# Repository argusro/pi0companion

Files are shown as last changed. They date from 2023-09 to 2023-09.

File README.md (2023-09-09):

<!DOCTYPE html>
<html lang="en">
<head>
    <meta charset="UTF-8">
    <meta name="viewport" content="width=device-width, initial-scale=1.0">
</head>
<body>

<h1>π0companion</h1>

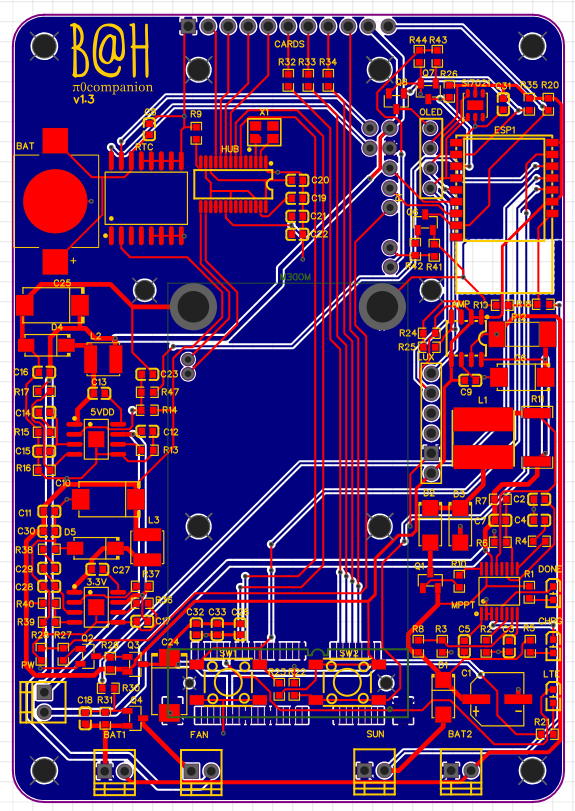
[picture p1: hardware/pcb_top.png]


<p>
We all love our Raspberry Pi projects, and most time using a good PSU is enough to have reliable system.<br>
But what if you want to take your project mobile of off-grid, how to manage the power requirements and beyond that, be able to trust in the continuous operation of your device.<br>
Thinking on that this companion circuit was created. It can be used on usual size Raspberry Pi boards, but considering power consumption for off-grid project this version focus on Pi Zero, any versions.<br>
It adds the following features to your Pi:
</p>

<ul>
    <li><strong>Modem Mini Pcie slot:</strong> 4G modem is a must for any mobile project, and it can include GPS. Based on EG25G/EC25 from Quectel.</li>
    <li><strong>Micro-controller IO/s and Power MGMT:</strong> To add a second layer of IOs and also working as a Watch Dog to the system, a ESP-M2 is used in parallel with the Pi.</li>
    <li><strong>MPPT Charger:</strong> For when a constant power supply is not available, the circuit includes a simple MPPT charger that can be used with Solar Panel or Wind generator.</li>
    <li><strong>HMI:</strong> Direct access to the micro-controller using push buttons and Oled display.</li>
    <li><strong>Environment sensors:</strong> Temperature, humidity, solar/input voltage, battery power monitoring, I2C slot expansion.</li>
    <li><strong>Extra Storage:</strong> Depending on the storage requirement, having extra space to store media and avoid over-using the Pi's main SD is recommended, so an SD card reader is available.</li>
    <li><strong>USB Hub:</strong> Since Pi Zero has a single USB port a local hub is added, to be shared with Pcie modem, SD Card and an extra USB-A Port.</li>
    <li><strong>RTC:</strong> As internet connection is not always available, and even when is it takes some time after boot to adjust the system clock, a local RTC clock was added.</li>
</ul>

<p>The provided code is for the local micro-controller, and the companion code for the Pi for burning ESP and also communicate with the base board.</p>

<h2>Getting Started</h2>

<p>To get started with this project, follow these steps:</p>

<ol>
    <li><strong>Hardware:</strong> You can use development modules for each sensor and the micro-controller, or assemble the suggested PCB.</li>
    <li><strong>Software:</strong> 
    <ul><strong>Compilation:</strong>  This code is for Arduino IDE and requires the following extra libraries to be installed:</li>
    <ul>
        <li><strong>ESP8266WiFi</strong> | You first need to add ESP8266 support on Arduino IDE | https://arduino-esp8266.readthedocs.io/en/latest/installing.html</li>
        <li><strong>Adafruit INA219</strong> | INA219 DC current and voltage sensor | https://github.com/adafruit/Adafruit_INA219</li>
        <li><strong>Arduino Json</strong> | To supports JSON serialization and deserialization | https://arduinojson.org/?utm_source=meta&utm_medium=library.properties</li>
        <li><strong>SparkFun Si7021</strong> | Si7021 Temperature and Humidity sensor | https://github.com/sparkfun/SparkFun_Si7021_Arduino_Library</li>
        <li><strong>Adafruit SSD1306</strong> |  Monochrome OLEDs based on SSD1306 drivers | https://github.com/adafruit/Adafruit_SSD1306</li>
        <li><strong>Adafruit GFX</strong> | Core graphics library for Adafruit displays | https://github.com/adafruit/Adafruit-GFX-Library</li>
        <li><strong>LittleFS</strong> | A little fail-safe filesystem designed for micro-controllers. | https://github.com/littlefs-project/littlefs</li>
    </ul></ul>
    <ul>
    <strong>Deploying:</strong> 
    <ul><li>To burn the code in the circuit is straightforward if you are using a commercial ESP8266/ESP8285 module.</li>
    <li> For the suggested circuit, after compiling copy the .bin file to the Pi and use the esp_burn.sh to upload the code.
    </ul></li></ul>
</ol>

<h2>Usage</h2>

<p>Taking your Pi on the road or just outside adds some other possibilities from the already vast options of use, such as:</p>

<ul>
    <li><strong>Outdoor camera:</strong> Use for security, wildlife or timelapse camera is one obvious application with the Pi Camera modules.</li>
    <li><strong>Mobile Hotspot:</strong> We have a Pi with 4G module, you can create a hotspot very easily.</li>
    <li><strong>IoT Gateway:</strong> You can have multiple remote sensors using WiFi from the Pi to reach the Internet.</li>
    And many other projects.
</ul>

<h2>Observations</h2>

<ul>
    <li>If a commercial modules is used it can be either ESP8266 or ESP8285. In case of the suggested PCB uses ESP8285. In any case, select the correct hardware when compiling.</li>
    <li>PCB was design to fit in a 125x105x70mm plastic case, that are widely available online. You can also fit the batteries and any other module that you will need to use.<br>
    A 3D design [pcb_support.stl] is provided to mount the board inside the suggested case, it can be glued or use screws through the bottom of the case.</li>
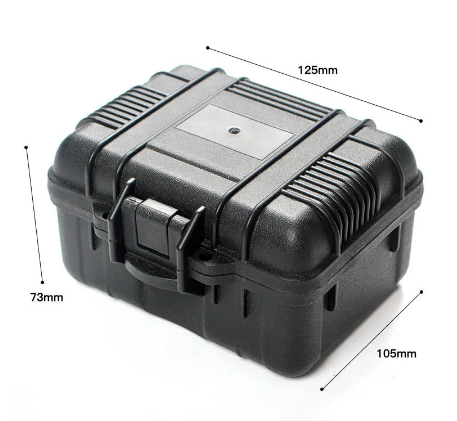
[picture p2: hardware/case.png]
    
    <li>To avoid soldering the required connections to the Pi, pogo testing pins can be used to reach GPIO and USB.</li>
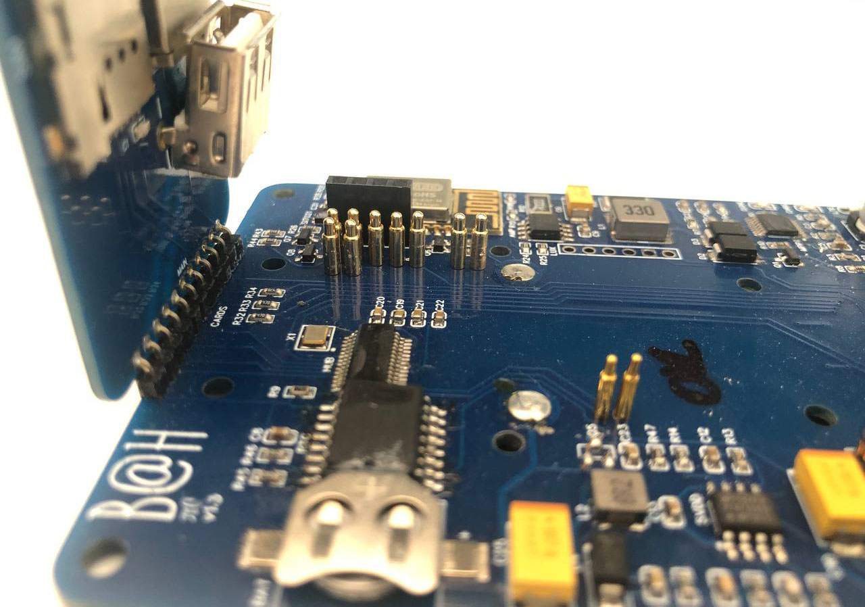
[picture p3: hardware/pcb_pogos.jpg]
    
    <li>To facilitate access a few components were move to a second board, like SD slot, SIM card slot, ESP reset button and USB-A port. This board should be assembled perpendicular to the main PCB.</li>
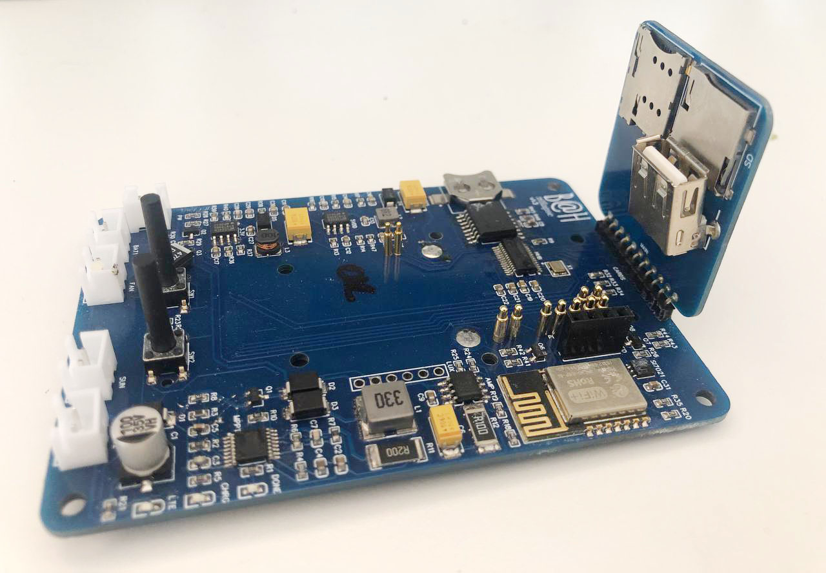
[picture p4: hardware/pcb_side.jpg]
    
    <li>Battery should be a dual cell Li-ion for example 18650, to operate in 8.4V. Two connections for battery are available in parallel to increase capacity. Circuit can also be altered to operate in 12V, just requiring to adjust the MPPT charger output voltage.</li>
    <li>For charging in case of indoor use, any PSU from 18V to 28V with 1A can be used. Charger is configured to provide maximum 1A, but it could be changed to up 5A with some components adjustments and pcb redesign.</li>
</ul>

<h2>Future Work</h2>
<ul>
    <li><strong>Connectivity:</strong> Currently the code will disable the WiFi radio from ESP8285 to reduce power consumption, but a local wireless web interface could be added.</li>
    <li><strong>Micro-controller upgrade:</strong> Plans to change to ESP32 are on the way, allowing more IOs and also Bluetooth connectivity.</li>
    <li><strong>EOL parts:</strong> Some of the components used are reaching their End-Of-Life, but they are still widely available. In any case, newer recommended substitutes should be used in future versions</li>
</ul>

<h2>Contributing</h2>

<p>If you want to contribute to this project, please follow these guidelines:</p>

<ol>
    <li>Fork the repository.</li>
    <li>Create a new branch for your feature or bug fix.</li>
    <li>Make your changes and test them thoroughly.</li>
    <li>Create a pull request to submit your changes.</li>
</ol>

<h2>License</h2>

<p>This project is licensed under the <a href="https://www.gnu.org/licenses/gpl-3.0.html">GNU General Public License v3.0 (GPL-3.0)</a>.</p>
<!--
<h2>Acknowledgments</h2>

<ul>
    <li>Special thanks to <a href="CONTRIBUTORS.md">contributors</a> who have helped with this project.</li>
    <li>Icons made by <a href="https://www.example.com/">Author</a> from <a href="https://www.flaticon.com/">www.flaticon.com</a>.</li>
</ul>
-->
<h2>Contact</h2>

<p>For questions or support, please contact us at <a href="mailto:argusr@me.com">argusr@me.com</a>.</p>

</body>
</html>

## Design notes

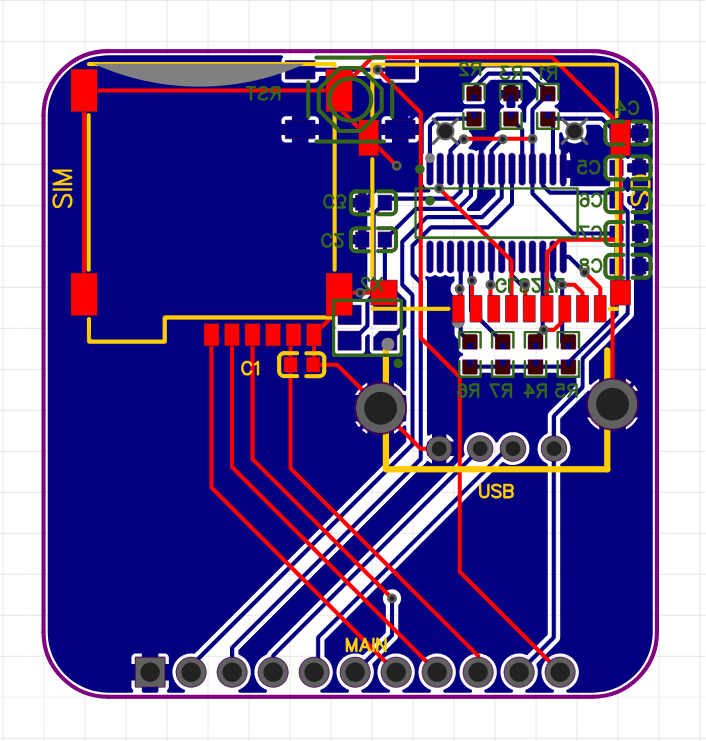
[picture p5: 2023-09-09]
hardware/pcb_cards.png

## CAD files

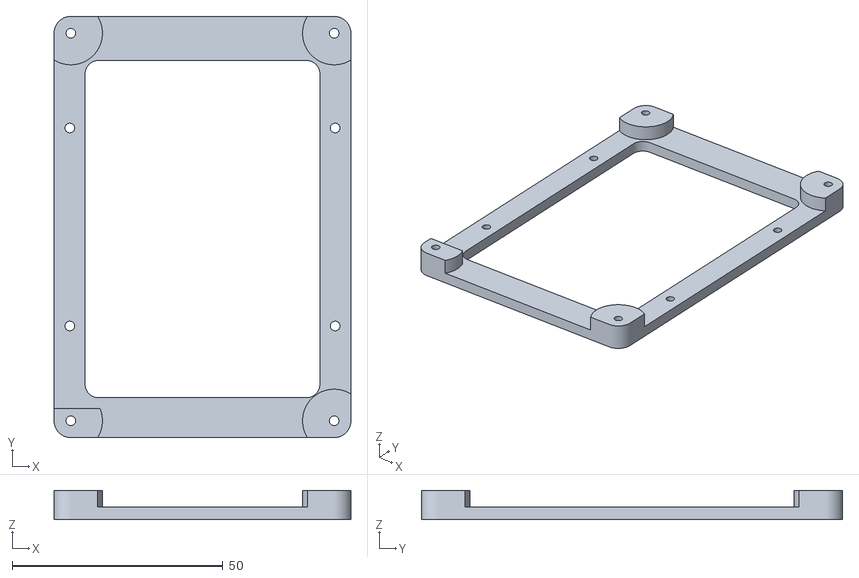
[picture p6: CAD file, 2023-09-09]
hardware/pcb_support.stl
70.5 x 100.0 x 7.00

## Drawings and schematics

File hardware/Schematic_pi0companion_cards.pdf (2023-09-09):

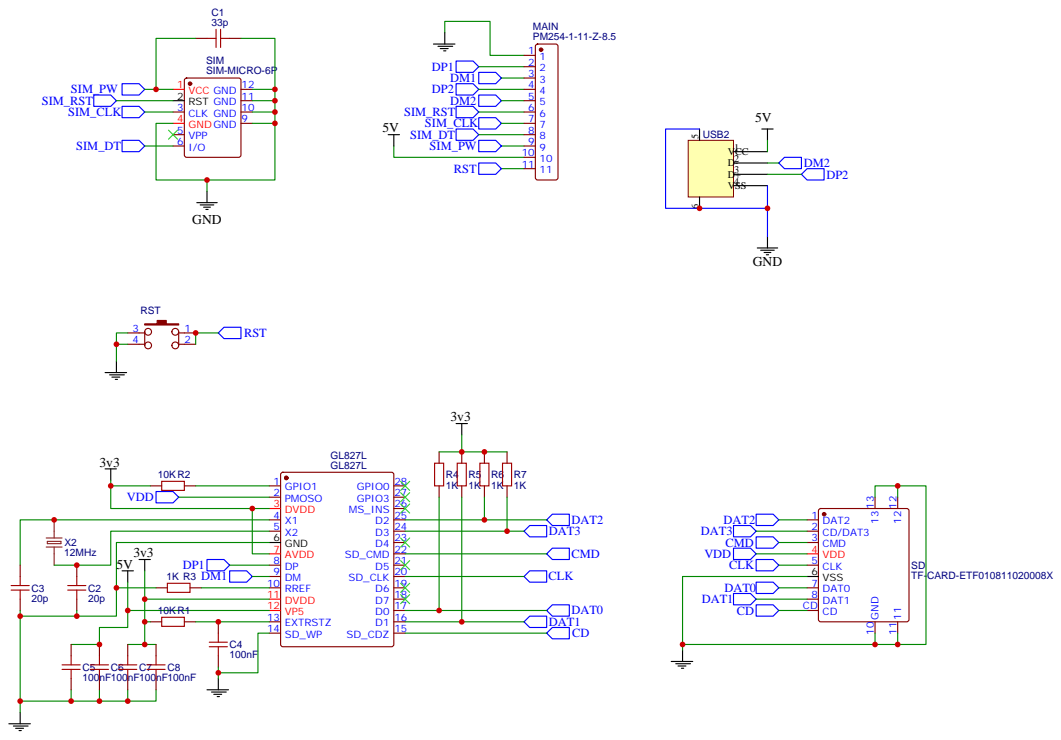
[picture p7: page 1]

Drawn By: Argus Rosenhaim

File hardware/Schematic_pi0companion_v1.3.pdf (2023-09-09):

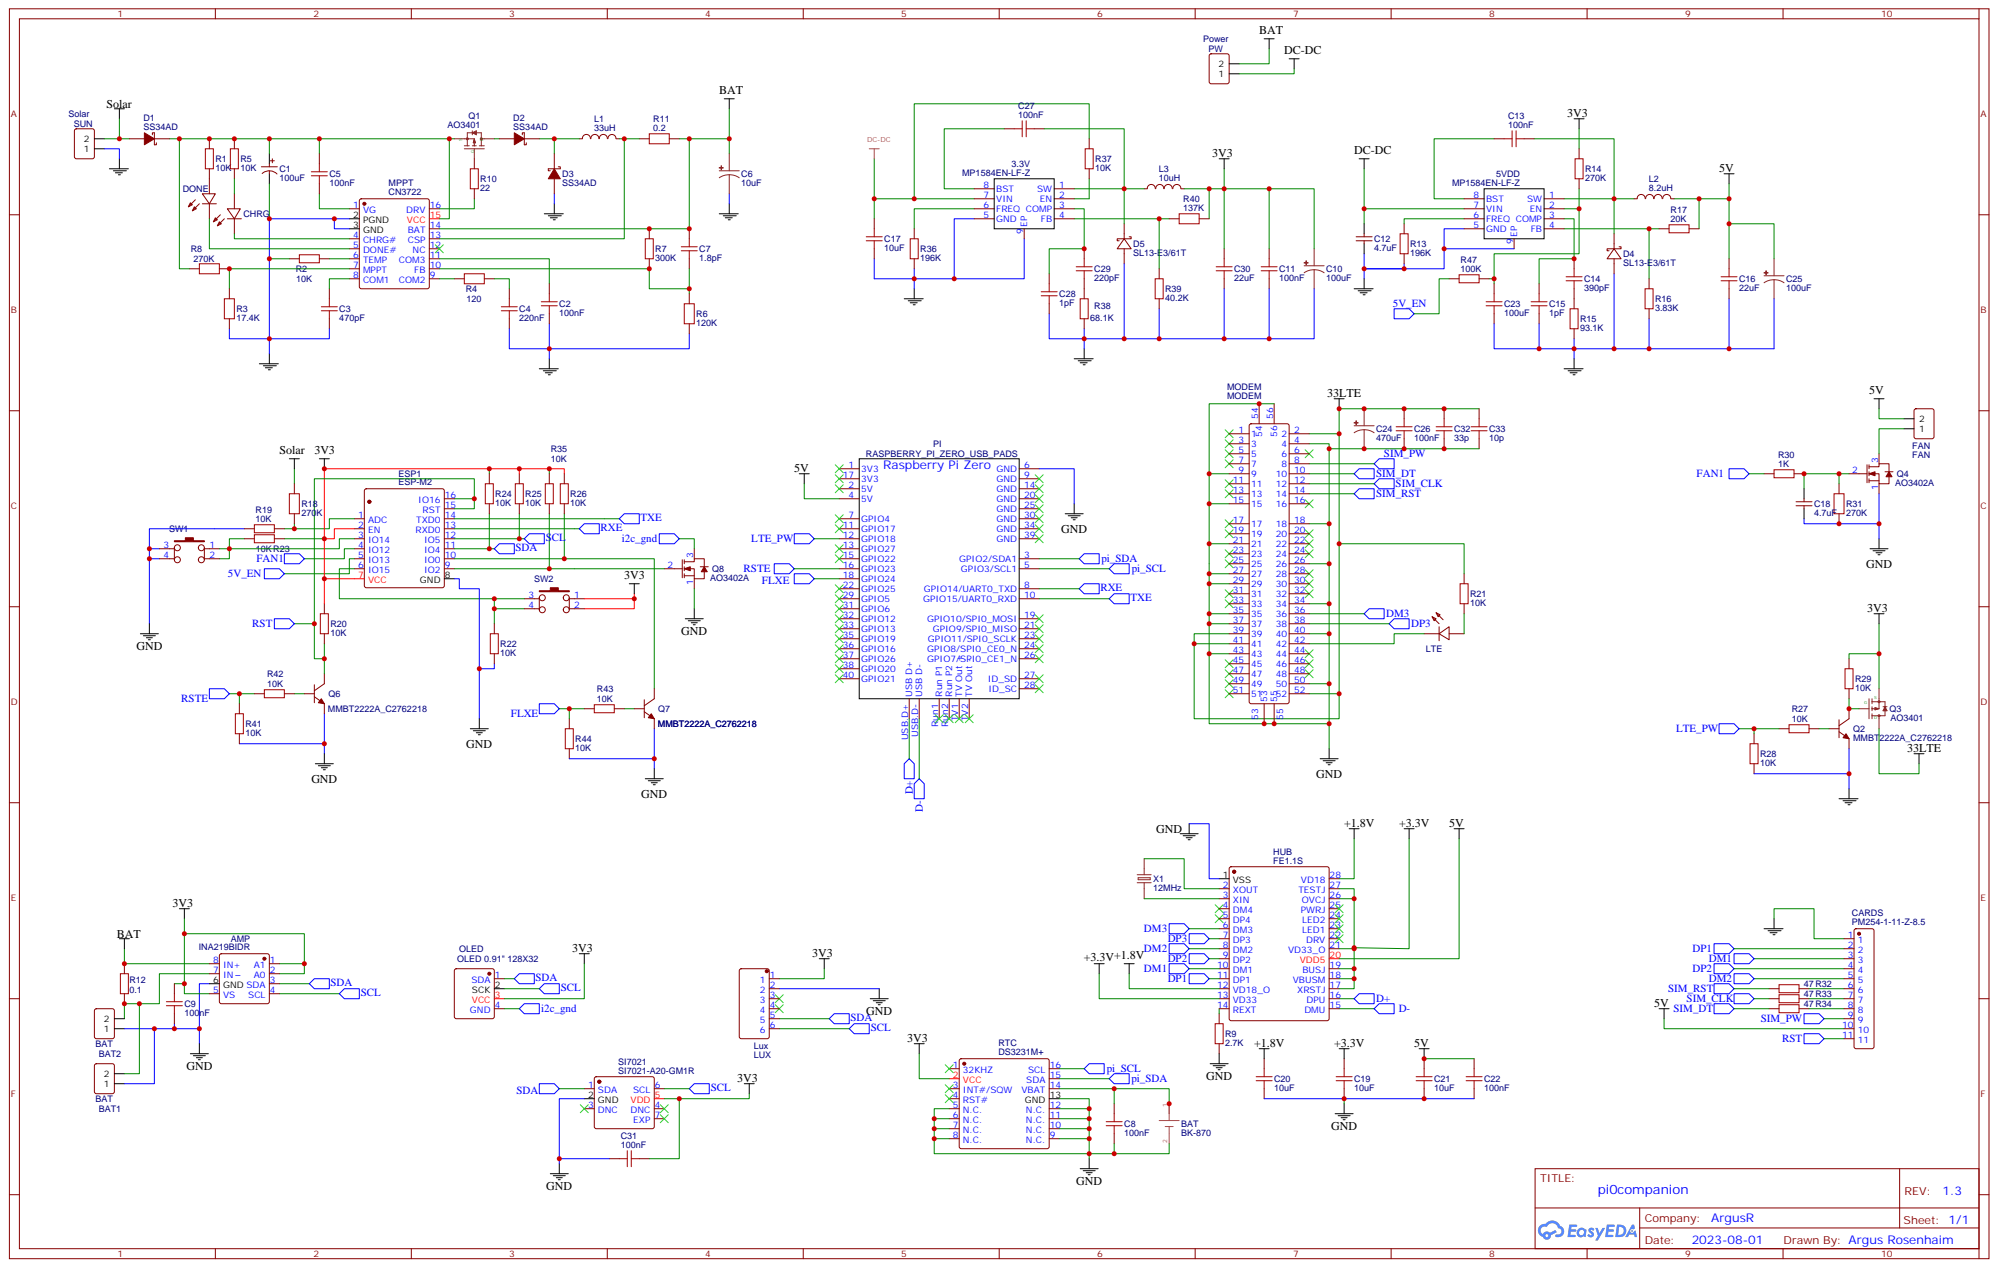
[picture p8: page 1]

MPPT
FB 10 COM3 11 NC 12 CSP 13 BAT 14 VCC 15 DRV 16

Drawn By: Argus Rosenhaim

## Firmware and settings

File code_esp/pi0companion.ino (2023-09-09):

#define Firmware 3.06
#define board_version 1.3
// #define DEBUG

// Iniciate libraries
#include <ESP8266WiFi.h>
#include <Adafruit_INA219.h>
#include <ArduinoJson.h>
#include "SparkFun_Si7021_Breakout_Library.h"
#include <Wire.h>
#include <Adafruit_GFX.h>
#include <Adafruit_SSD1306.h>
#include "LittleFS.h"
#include "logo.h"

// Oled display definitions
#define SCREEN_WIDTH 128 // OLED display width, in pixels
#define SCREEN_HEIGHT 32 // OLED display height, in pixels
#define OLED_RESET     -1 // Reset pin # (or -1 if sharing Arduino reset pin)

// Instantiate Sensors
Adafruit_SSD1306 display(SCREEN_WIDTH, SCREEN_HEIGHT, &Wire, OLED_RESET);
Adafruit_INA219 ina219(0x45);
Weather sensor;

// Time related variables
uint32_t mLastTime = 0;
uint32_t sampleLastTime = 0;
uint32_t last_comm = 0;
long lastDebounceTime = 0;
long lastDebounceTime2 = 0;

// GPIO definitions
#define SW1 14
#define SW2 15
#define fan_in 12
#define soc_pw_pin 13
#define i2c_gnd 2

// Control variables
#define debounceDelay 500
#define wait_before_sleep 15
#define samples 31
#define min_fan_speed 400
float min_voltage=6.8; // Voltage when the system should go in protection mode

// SoC power variables
int count_down = wait_before_sleep - 2;
int count_to_wakeup = 0;
bool SoC_PW = true;
long sleep_period = 0;
bool pi_sleeping = false;
long pi_sleep_start = 0;
bool pi_down = false;
bool low_power_detected = false;
long low_power_sleep = 0;
int low_power_counter = 0;
bool power_off_display = false;
long power_cycle_waiting = 0;
int power_cycle_count = 0;
bool power_cycling = false;
bool ckt_hot = false;
bool wakeup = false;

// Array of samples for each sensor
float hum[samples];
float temp[samples];
float current_mA[samples];
float loadvoltage[samples];
float power_mW[samples];
float solar_v[samples];

// Average variable for each sensor
int valid_samples = 1;
float hum_avg;
float temp_avg;
float current_mA_avg;
float loadvoltage_avg;
float power_mW_avg;
float solar_v_avg;
float busvoltage = 0;
float shuntvoltage = 0;

// byte error, address;
// bool booting = false;
// bool fanin = false;

// Define functions for buttons interruption
void ICACHE_RAM_ATTR switch_1();
void ICACHE_RAM_ATTR switch_2();

// Iniciate variable for device name
String DEVICE = "";

// Variables for menu operation
String confirm_change;
long change_time;
bool new_change_state = false;
bool start_change = false;

// Mobile operators options for menu
char *operators[] = {"Vivo","Claro","Tim","Oi","Vodafone","ThingsMobile"};
#define total_operators 6
int op_id = 0;

void setup() {
  // Disable ESP8266 Radio
  WiFi.forceSleepBegin();
  // Set GPIO modes
  pinMode(SW1, INPUT);
  pinMode(SW2, INPUT);
  pinMode(fan_in, OUTPUT);
  pinMode(soc_pw_pin, OUTPUT);
  pinMode(i2c_gnd, OUTPUT);
  // Power up Pi
  pi_power(true);
  // Power up I2C sensors
  i2c_power(true);
  // Set serial
  Serial.begin(115200);
  Serial.println();
  // Initiate ESP filesystem
  if (!LittleFS.begin()) {
    Serial.println("{'error':'An Error has occurred while mounting LittleFS'}");
    return;
  }
  // Call function to update values stored in the filesystem
  update_from_fs();
  // Initiate Oled display
  display.begin(SSD1306_SWITCHCAPVCC, 0x3C);  // initialize with the I2C addr 0x3C (for the 128x32)
  display.setRotation(2);
  display.clearDisplay();
  // Call logo, stored in logo.h
  display.drawBitmap(0, 0, bah_TL, 128, 32, WHITE);
  display.display();
  delay(3000);
  // Display device name and firmware version
  if (DEVICE.length() > 8 ) display.setTextSize(2);
  else display.setTextSize(3);
  display.setTextColor(WHITE);
  display.clearDisplay();
  display.setCursor(0, 0);
  display.print(DEVICE);
  display.setTextSize(1);
  display.setCursor(100, 24);
  display.print(Firmware);
  display.display();

  delay(3000);
  // Iniciate the interruption watch for the buttons
  attachInterrupt(SW1, switch_1, FALLING);
  attachInterrupt(SW2, switch_2, RISING);
  // Initiate the sensors
  sensor.begin();
  // comment line 67 on SparkFun_Si7021_Breakout_Library.cpp to remove HTU21D Found message
  ina219.begin();
  // Print on serial the wake up message
  uc2pi("boot","uc");
  // Start the internal watchdog
  ESP.wdtDisable();
}

void loop() {
  // Feed the watchdog beast
  ESP.wdtFeed();
  // Check for incoming serial messages from Pi
  if (Serial.available()) {
    serialEvent();
  }
  // If Pi is not in sleeping mode, read the sensors every 200ms
  if(!pi_sleeping){
    if (millis() - sampleLastTime > 200) {
      readSensors();
      sampleLastTime = millis();
    }
  }
  // At every second when Pi sleep command is issued
  if (millis() - mLastTime > 1000) {
    if(pi_sleeping){
//      if (sleep_period > 44000000) sleep_period = 0;  // second protection agaist sleeping more than 12h
      // If the oled is still on
      if(!power_off_display){
        // Clear and update the countdown on the oled display
        display.clearDisplay();
        display.setCursor(0, 0);
        display.print((sleep_period - (millis() - pi_sleep_start))/1000 );
        // If Pi power is still up, display a second countdown for the power down
        if(!pi_down){
          display.setCursor(0, 10);
          display.print((wait_before_sleep*1000 - (millis() - pi_sleep_start))/1000 );       
        }
        display.display();
      }
    }
    // If a power cycle was issued, decrease its counter
    if(power_cycling) power_cycle_count--;    
    mLastTime = millis();
  }
  // Call a few functions on every loop
  update_oled();
  pi_standby();
  pi_power_cycle();
  fan_monitoring();
  monitor_menu_changes();
}

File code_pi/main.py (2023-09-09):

#========================================================================================
#
#   FastAPI App to send messages to Micro-controller(uC)
#
#   This script creates an API to interact with the main board
#
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
#   Dependencies: 
#     apt install fastapi setproctitle uvicorn gunicorn
#     
#
#   Use:  manual: execute run_app.sh
#         service: copy serial_api.service to /etc/systemmd/system/ and activate 
#
#   Version: 1.0 - 09/2023
#   Author: ArgusR <argusr@me.com>
#
#========================================================================================
# Set process name on OS
from setproctitle import setproctitle
setproctitle('serial_api')

import os
import serial
import json
import socket
import logger
import datetime
import subprocess
from fastapi import FastAPI

# Setup the logging
log, master_log = logger.set_logs(os.path.basename(__file__))

# Configuration and database as json files
DB_MGMT="/home/pi/db/mgmt.json"
DB_WEB="/home/pi/db/web.json"

device = socket.gethostname()

app = FastAPI()

# Function to convert variable types
def str_to_bool(s):
    if s == "True":
         return True
    elif s == "False":
         return False
    else:
         raise ValueError

# Function to send serial messages, log and deal with responses.
def get_response(data):
  MGMT = json.loads(open(DB_MGMT).read())
  uC_burning = MGMT["uC_burning"]
  resp_json = {"message":None}
  if uC_burning == "False":
    # Stop pair script responsible for monitoring uC messages
    subprocess.call('sudo pkill -f serial_monitor', shell=True)
    ser = serial.Serial('/dev/serial0', 115200, timeout=1)
    if ser.isOpen():
      ser.write(data.encode('ascii'))
      ser.flush()
      logger.main('debug',"Sent: " + str(data),log, master_log)
      try:
        resp = ser.readline().decode()
        resp_json = json.loads(resp[:-2])
        logger.main('debug',"Received: " + str(resp_json),log, master_log)
        if 'message' in resp_json:
          logger.main('info',resp_json["message"],log, master_log)
        elif 'error' in resp_json:
          logger.main('error',resp_json["error"],log, master_log)
      except Exception as e:
        logger.main('error',"Exception: " + str(e),log, master_log)
        pass
    else:
      logger.main('error',"Serial error",log, master_log)
    ser.close()
    subprocess.Popen('/home/pi/serial_monitor')
  else:
    logger.main('error',"uC currently receiving update, your command will be ignored: " + str(data),log, master_log)
  return resp_json

# Request sensor values from uC
@app.get("/telemetry")
def telemetry():
  msg = {}
  msg["data"] = "telemetry"
  data=json.dumps(msg)
  resp_json = get_response(data)
  return resp_json

# Set fan speed on uC
@app.get("/fan")
def fan(speed: int):
  msg = {}
  msg["fan"] = speed
  data=json.dumps(msg)
  resp_json = get_response(data)
  if 'fan' in resp_json:
    logger.main('info',"Fan speed set to " + str(resp_json["fan"]),log, master_log)
  return resp_json

# Set Pi to sleep, for specific period or until the next day
@app.get("/sleep")
def sleep(interval=None):
  if interval is None:
    WEB = json.loads(open(DB_WEB).read())
    tl_start = int(WEB["shoot"]["start"])
    now = datetime.datetime.now()
    try:
      wake_up = datetime.datetime(now.year,now.month,now.day+1,tl_start)
    except:
      wake_up = datetime.datetime(now.year,now.month+1,1,tl_start)
    tdelta = wake_up - now
    tdelta_sec = int(tdelta.total_seconds())
    logger.main('info',"Sleep interval: " + str(tdelta_sec),log, master_log)
    if tdelta_sec > 64800:  # if is more than 18h, is possibly after midnight
      logger.main('warning',"Trying to sleep more than accepted: " + str(tdelta_sec),log, master_log)
      wake_up = datetime.datetime(now.year,now.month,now.day,tl_start)
      tdelta = wake_up - now
      tdelta_sec = int(tdelta.total_seconds())
      logger.main('info',"Recalculated to: " + str(tdelta_sec),log, master_log)
    sleep_time = tdelta_sec-900  # boot 15 min before the timelapse start time
    if sleep_time < 0:  # avoid negative time
      logger.main('error',"Got a negative value for sleep interval, will replace with 1 min: " + str(sleep_time),log, master_log)
      sleep_time = 60
  else:
    sleep_time = interval

  msg = {}
  msg["sleep"] = sleep_time
  data=json.dumps(msg)
  resp_json = get_response(data)
  if (resp_json["message"].startswith("Wakeup in")):
    logger.main('info',resp_json["message"],log, master_log)
    if interval is None:
      subprocess.call("/home/pi/data_traffic", shell=True)
      subprocess.call("/home/pi/data_traffic clear", shell=True)
    subprocess.call("sudo shutdown now", shell=True)
  else:
    logger.main('error',"Didn't get a response from uC, no shutdown this time",log, master_log)
  return resp_json

# Return to uC confirming changing received form menu
@app.get("/confirm_change")
def confirm_change(item: str):
  msg = {}
  msg["confirm"] = item
  data=json.dumps(msg)
  resp_json = get_response(data)
  logger.main('debug',"Change confirmation sent to uC: " + str(data),log, master_log)
  return resp_json

# Send message to uC display that system is going down
@app.get("/shutdown")
def shutdown():
  msg = {}
  msg["going_down"] = True
  data=json.dumps(msg)
  resp_json = get_response(data)
  return resp_json

# Return camera setup to uC to update menu
@app.get("/timelapse")
def timelapse(start: int,end: int,interval: int):
  msg = {}
  msg["setup_tl"] = {}
  msg["setup_tl"]["start"] = start
  msg["setup_tl"]["end"] = end
  msg["setup_tl"]["interval"] = interval
  data=json.dumps(msg)
  resp_json = get_response(data)
  return resp_json

# Return wifi and streaming setup to uC menu
@app.get("/mgmt")
def mgmt(wifi: bool,stream: bool):
  msg = {}
  msg["setup_mgmt"] = {}
  msg["setup_mgmt"]["wifi"] = wifi
  msg["setup_mgmt"]["stream"] = stream
  data=json.dumps(msg)
  resp_json = get_response(data)
  return resp_json

# Set uC to monitor or not Pi messages
@app.get("/watchdog")
def watchdog(enable: bool):
  msg = {}
  msg["watchdog"] = enable
  data=json.dumps(msg)
  resp_json = get_response(data)
  return resp_json

# Single function to update all menus in uC
@app.get("/update_uc")
def update_uc():
  MGMT = json.loads(open(DB_MGMT).read())
  wifi = str_to_bool(MGMT["wifi"])
  stream = str_to_bool(MGMT["stream"])
  mgmt(wifi,stream)

  WEB = json.loads(open(DB_WEB).read())
  shoot_interval = int(WEB["shoot"]["interval"])
  shoot_start = int(WEB["shoot"]["start"])
  shoot_stop = int(WEB["shoot"]["stop"])
  timelapse(shoot_start,shoot_stop,shoot_interval)

# Function to call I2C reset on uC
@app.get("/i2c_clean")
def i2c_clean():
  msg = {}
  msg["i2c_clean"] = True
  data=json.dumps(msg)
  resp_json = get_response(data)

# Main API function that send the hostname to uC
def main():
  msg = {}
  msg["boot"] = device
  data=json.dumps(msg)
  resp_json = get_response(data)
  update_uc()

main()

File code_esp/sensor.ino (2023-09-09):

// variable to indicate when charging voltage is available
bool have_sun = true;

// Function to deal with button 1 interruption
void ICACHE_RAM_ATTR switch_1() {

  ESP.wdtFeed();

  int reading = digitalRead(SW1);

  if (reading == LOW) {
    // Debounce routine
    if ((millis() - lastDebounceTime) > debounceDelay) {
      lastDebounceTime = millis();
      // If display is off, turn it on
      if(power_off_display and (pi_down or low_power_detected)) {
        display.ssd1306_command(SSD1306_DISPLAYON); 
        power_off_display = false;
      }
      // If menu is telecom operator page, this section confirms the new value
      else if(change_op and selector == 2){
        change_op = false;
        char new_op[1];
        itoa(op_id,new_op,10);
        // Serial.println(new_op);
        writeFile(LittleFS, "/telecom.txt", new_op);
        uc2pi("telecom",operators[op_id]);
        change_time = millis();
        confirm_change = "op";
      }
      // If any other menu page, button 1 increase page
      else{
        if(selector == 0){
          page++;
          if(page > total_pages-1) page=0;
        }
        // In case of any of the confirmations bellow, button 1 confirms the option. 
        else if(ask_reboot or ask_shutdown or power_cycle) confirm = true;
        // In any other case, button 1 alters the value
        else toogle = true;
      }
    }
  }
}

// Function to deal with button 2 interruption
void ICACHE_RAM_ATTR switch_2() {

  ESP.wdtFeed();

  int reading = digitalRead(SW2);

  if (reading == HIGH) {
    // Debounce routine
    if ((millis() - lastDebounceTime2) > debounceDelay) {
      lastDebounceTime2 = millis();
      // When display is on
      if(!power_off_display) {
        // If Pi is supposed to be off, button 2 turn off display
        if(pi_down){
          display.ssd1306_command(SSD1306_DISPLAYOFF); 
          power_off_display = true;
        }
        else if(low_power_detected){
          display.ssd1306_command(SSD1306_DISPLAYOFF); 
          power_off_display = true;
        }
        else{
          // In the menu, button 2 will cancel the confirmations below
          if(ask_reboot or ask_shutdown or power_cycle) {
            page = 3;
            selector = 0;
            ask_reboot = false;
            ask_shutdown = false;
            power_cycle = false;
          }
          // In any other case, button 2 will change se selection in the same page
          else {
            selector++;
            if(selector > page_options-1) selector=0;
          }
        }
      }
    }
  }
}

// // Sensor variables are saved in an array, this function return the average of this array
// float average (int * array, int len)  // assuming array is int.
// {
//   long sum = 0L ;  // sum will be larger than an item, long for safety.
//   for (int i = 0 ; i < len ; i++)
//     sum += array [i] ;
//   return  ((float) sum) / len ;  // average will be fractional, so float may be appropriate.
// }

// Read all sensors with this function
void readSensors() {
  // Shift arrays of samples
  for (int sample = 0; sample < samples-1; sample++){
    hum[sample]=hum[sample + 1];
    temp[sample]=temp[sample + 1];
    current_mA[sample]=current_mA[sample + 1];
    power_mW[sample]=power_mW[sample + 1];
    loadvoltage[sample]=loadvoltage[sample + 1];
    solar_v[sample]=solar_v[sample + 1];
  }
  // Add new sample to the last position
  hum[samples-1] = sensor.getRH();
  temp[samples-1] = sensor.getTemp();  
  current_mA[samples-1] = ina219.getCurrent_mA();
  power_mW[samples-1] = ina219.getPower_mW();
  busvoltage = ina219.getBusVoltage_V();
  shuntvoltage = ina219.getShuntVoltage_mV();
  loadvoltage[samples-1] = busvoltage + (shuntvoltage / 1000);

  float Analog0 = analogRead(A0);
  solar_v[samples-1] = (Analog0 / 1024) * 27;
  // Zero any noise from solar input voltage
  if (solar_v[samples-1] < 3)
    solar_v[samples-1] = 0;
  float solar_delta = abs(solar_v[samples-1] - solar_v[samples-2])/solar_v[samples-1];
  // Reset the valid samples used to make the avarage in case of subtle change in solar input.
  if(!isnan(solar_delta)) {
    if ( solar_delta > 0.1){
      valid_samples = 1;
    }
  }
  // // Reset the valid samples used to make the avarage in case of subtle change in power measurement
  // float power_delta = abs(power_mW[samples-1] - power_mW[samples-2])/power_mW[samples-1];  
  // if ( power_delta > 0.2){
  //   valid_samples = 1;
  // }
  
  // Reset average values
  hum_avg = 0;
  temp_avg = 0;
  current_mA_avg = 0;
  power_mW_avg = 0;
  loadvoltage_avg = 0;
  solar_v_avg = 0;

  // Sum all samples from each array  
  for (int sample = samples-1; sample >= samples-valid_samples; sample--){
    hum_avg += hum[sample];
    temp_avg += temp[sample];
    current_mA_avg += current_mA[sample];
    power_mW_avg += power_mW[sample];
    loadvoltage_avg += loadvoltage[sample];
    solar_v_avg += solar_v[sample];
  }
  
  // Divide each sum by the number of valid samples
  hum_avg /= valid_samples;
  temp_avg /= valid_samples;
  current_mA_avg /= valid_samples;
  power_mW_avg /= valid_samples;
  loadvoltage_avg /= valid_samples;
  solar_v_avg /= valid_samples;

  // Check for low power, waiting for 10 consecutive measurements to confirm
  if ( loadvoltage_avg < min_voltage) {
    low_power_counter++;
    if(low_power_counter > 10) low_power();
  }
  else low_power_counter=0;
 
  // Increase the number of samples used in the average for fast update on power on and subtle changes
  if(valid_samples < samples) valid_samples++;
}

// Function to serialize sensor values in a json structure
void sendSensors() {
  readSensors();
  StaticJsonDocument<400> doc;
  doc["Temperature"] = String(temp_avg, 2);
  doc["Humidity"] = String(hum_avg, 2);
  doc["Voltage"] = String(loadvoltage_avg, 2);
  doc["Current"] = String(current_mA_avg, 2);
  doc["Power"] = String(power_mW_avg, 0);
  doc["Solar"] = String(solar_v_avg, 2);
  doc["Uptime"] = String(millis() / 1000);

  serializeJson(doc, Serial);
//  serializeJsonPretty(doc, Serial);
  Serial.println();

}
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

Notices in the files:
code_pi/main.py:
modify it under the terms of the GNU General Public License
